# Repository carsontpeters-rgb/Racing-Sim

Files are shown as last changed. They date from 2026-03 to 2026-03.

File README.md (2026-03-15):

What is it?
Its a sim rig that I built from scratch. It has a steering wheel, gas, brake and clutch with a H pattern shifter. Its all built around a Teensy 4.1 that plugs straight into a PC via USB. The brake uses a load cell and a heavy spring to give it a realistic feel and the gas and clutch use position sensors with lighter springs. The steering wheel uses a magnetic encoder so it never wears out and its geared so you can get 720 degrees of rotation even though the sensor only measures 360. The shifter works with the same encoders, there is one for the X axis and one for the Y and they read the angles to see what gear its in.
How do you use it?
You use it by just plugging it in, the OLED screen will walk you through a calibration sequence so it knows where the gears are, where the steering wheel is and the pedal positions. It saves after so you dont need to do it again unless it starts acting up.
Why did I make it?
I made it because sim rigs are expensive and I figured I could make a nice one for cheaper, plus I learned a lot while working on the project and get a cool gaming controller out of it.
How do you build it?
Its a 3D printed rig with steel rods to support areas where just plastic would fail. The frame gets screw into my desk which is why there no way to mount it, it will be permant. Each pedal has a hall sensor and a magnet that measures how far the pedal is pressed and tells the microcontroller how much throttle to give, except the brake which uses a load cell run through a HX711 to amplify the signal. The steering column runs through 2 bearings with a gear in the middle so all the load goes through the frame and the gear turns the magnet to measure the angle. The H pattern shifter is similar to the wheel, it just has 2 encoders one for X and one for Y and based off those angles it tells the PC what gear its in. Its all run off 3.3V and a Teensy 4.1 with the code uploaded through Arduino IDE, you just have to change the USB type to keyboard mouse and joystick and hit upload.
Here is the onshape link for the cad
(https://cad.onshape.com/documents/68b4fea7a6f0c741230f520d/w/fb4024dbed9d682b8b255ca7/e/c212651a466c837dd5f70d13)
Note this desing wont work with Ps5 or Xbox unless you use a brooks wingman addappter

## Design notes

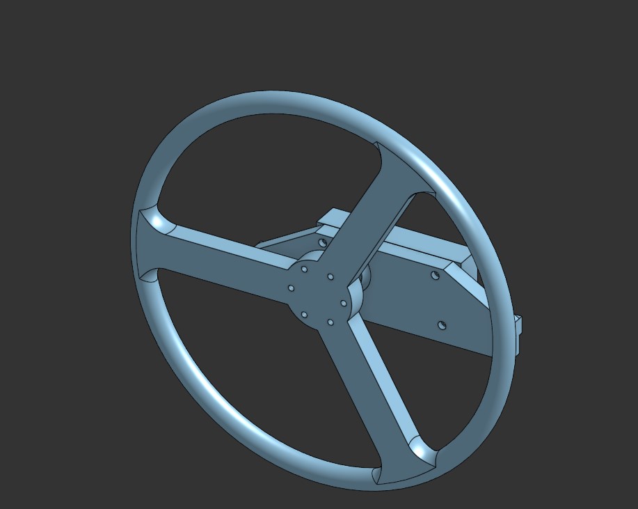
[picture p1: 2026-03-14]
Pictures/Steering.jpg

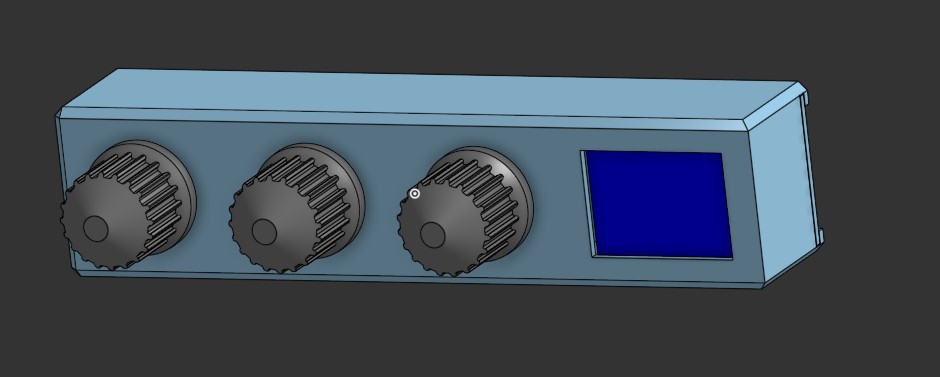
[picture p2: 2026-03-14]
Pictures/Display pannel.jpg

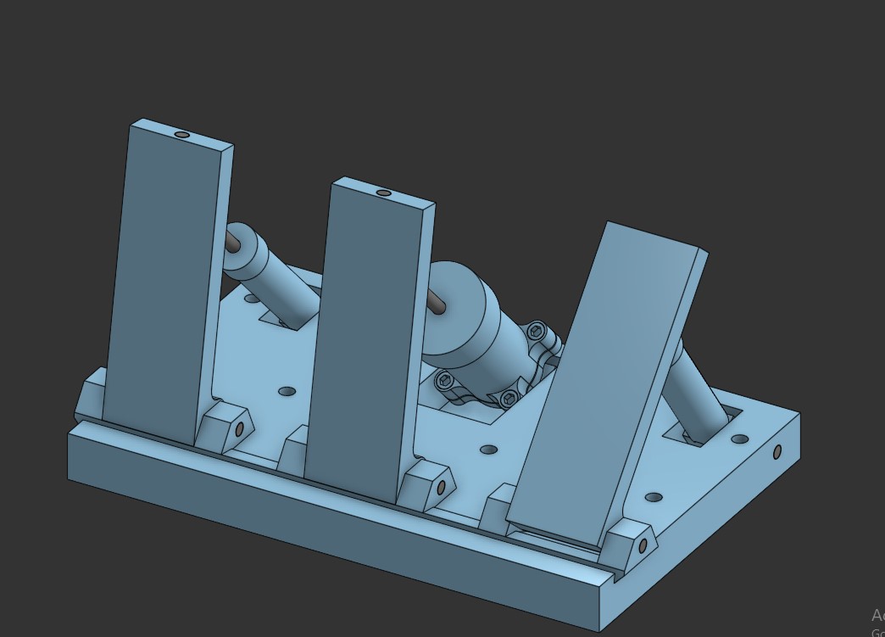
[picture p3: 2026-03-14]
Pictures/Pedals 2.jpg

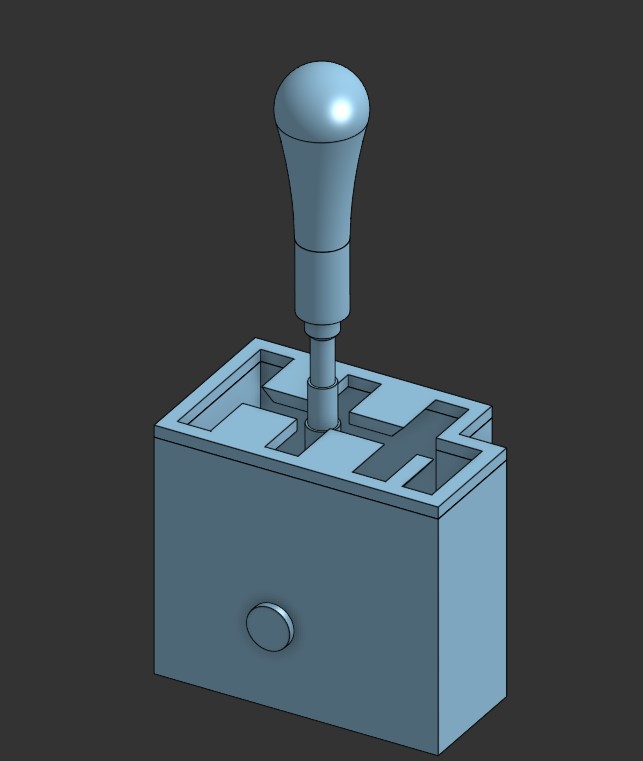
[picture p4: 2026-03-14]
Pictures/Stick.jpg

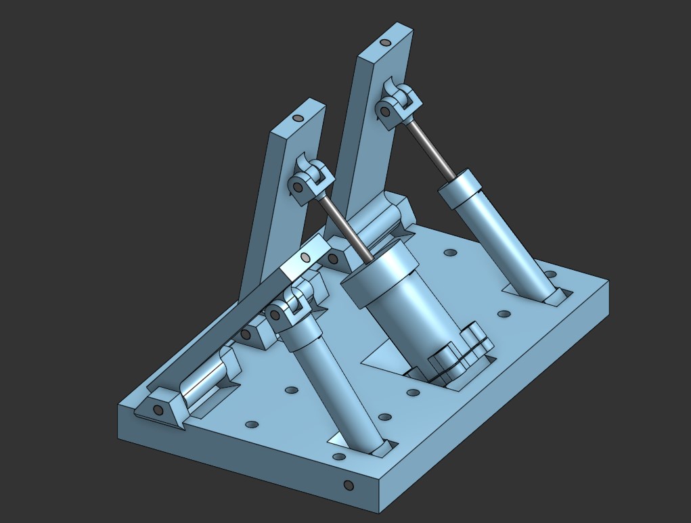
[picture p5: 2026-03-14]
Pictures/Pedals 1.jpg

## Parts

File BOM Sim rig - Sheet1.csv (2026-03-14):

Item Name | Discription | Quantity | Total Price | URL
Tension Springs | centering stick shift | 1 | $5.51 | https://www.aliexpress.com/item/1005009488489265.html?spm=a2g0o.cart.0.0.748638daWiuupG&mp=1
Rotery incoder Knob | setting ajutment knobs | 3 | $4.32 | https://www.aliexpress.com/item/1005008716778661.html?spm=a2g0o.cart.0.0.748638daWiuupG&mp=1
Oled Display | Display screen | 1 | $4.62 | https://www.aliexpress.com/item/1005006514489341.html?spm=a2g0o.cart.0.0.748638daWiuupG&mp=1
Steering wheel | Steering wheel | 1 | $42.57 | https://www.aliexpress.com/item/1005006066966347.html?spm=a2g0o.cart.0.0.748638daWiuupG&mp=1
HX711 | Load cell amplifier | 1 | $1.88 | https://www.aliexpress.com/item/1005006851380544.html?spm=a2g0o.cart.0.0.555038dasAW0UJ&mp=1
10Uf Capacitor | Capacitor | 1 | $4.46 | https://www.aliexpress.com/item/1005010409167964.html?spm=a2g0o.cart.0.0.555038dasAW0UJ&mp=1
Magnets | Magnets | 2 | $12.48 | https://www.aliexpress.com/item/1005010025118637.html?spm=a2g0o.cart.0.0.555038dasAW0UJ&mp=1
Ball Bearings | Bearings | 6 | $7.03 | https://www.aliexpress.com/item/10000314626783.html?spm=a2g0o.cart.0.0.555038dasAW0UJ&mp=1
49e Hall effect sensor | measures linear movement of magnets | 2 | $2.15 | https://www.aliexpress.com/item/32852539663.html?spm=a2g0o.cart.0.0.555038da9htNFP&mp=1
Load Cell | measures weight on break pedal | 1 | $9.18 | https://www.aliexpress.com/item/1005006039178981.html?spm=a2g0o.cart.0.0.555038da9htNFP&mp=1
100Nf Capacitors | Capacitors | 2 | $0.36 | https://www.aliexpress.com/item/1005006579533330.html?spm=a2g0o.cart.0.0.555038da9htNFP&mp=1
Teensy 4.1 | Micro Controller | 1 | $68.68 | https://www.aliexpress.com/item/1005004478114607.html?spm=a2g0o.cart.0.0.555038da9htNFP&mp=1
Magnetic Encoder | Measures Steering wheel rotation | 3 | $4.14 | https://www.aliexpress.com/item/1005008401280982.html?mp=1
TCA9548A | Ic2 Multiplexer | 1 | $0.57 | https://www.aliexpress.com/item/32904755017.html?spm=a2g0o.cart.0.0.555038da9htNFP&mp=1
Spring | Break reaturn Spring | 1 | $11.39 | https://www.aliexpress.com/item/1005007247817768.html?spm=a2g0o.cart.0.0.555038da9htNFP&mp=1
Spring | Gas+Clutch return spring | 2 | $8.49 | https://www.aliexpress.com/item/1005009816348235.html?spm=a2g0o.cart.0.0.555038da9htNFP&mp=1
Total Parts cost |  |  | $187.83
Total Parts cost after shipping+Tax |  |  | $236.00
Note all prices are in Cad

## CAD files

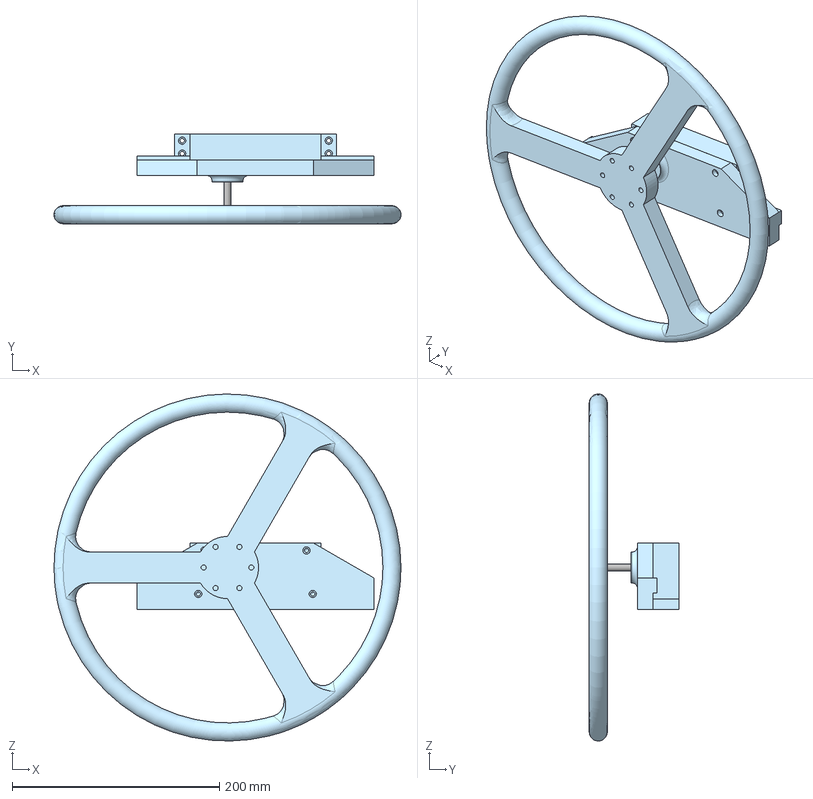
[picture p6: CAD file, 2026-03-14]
Cad Files/Assemblys/Steering wheel.step
335.0 x 86.5 x 335.0 mm
Spur gear (20 teeth)
Spur gear (10 teeth)

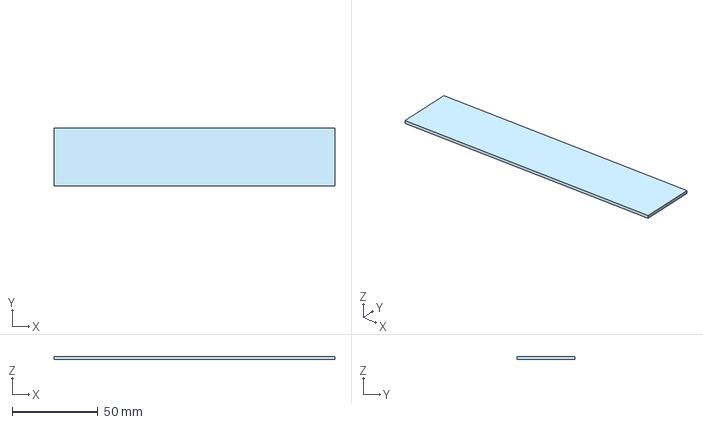
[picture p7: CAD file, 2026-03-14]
Cad Files/Control panel/Back pannel.step
163.5 x 33.5 x 1.75 mm

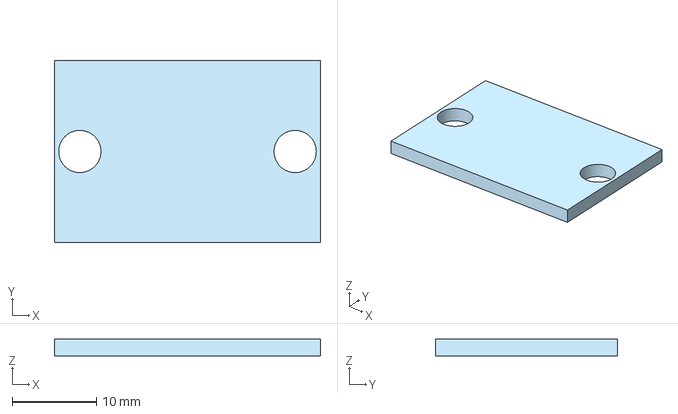
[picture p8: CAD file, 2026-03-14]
Cad Files/Electronics/IC2 Multiplexer.step
31.5 x 21.6 x 2.00 mm

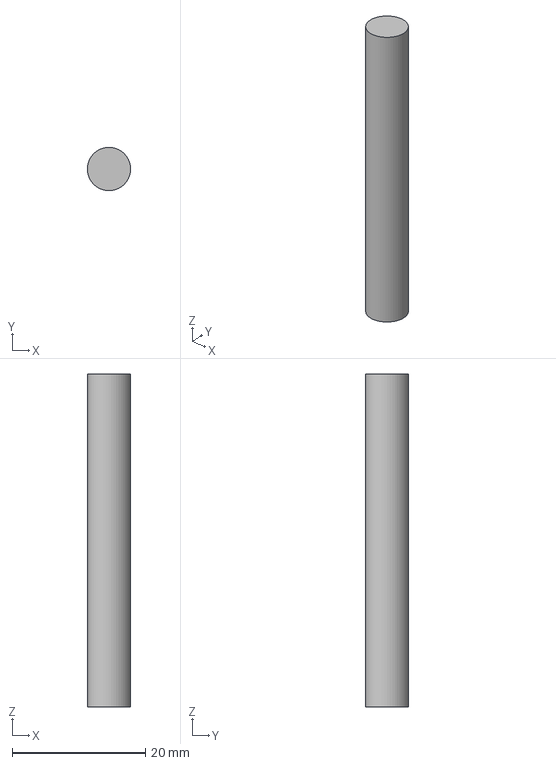
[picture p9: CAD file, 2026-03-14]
Cad Files/None Printed Parts/Steering Shaft.step
6.49 x 6.50 x 50.0 mm

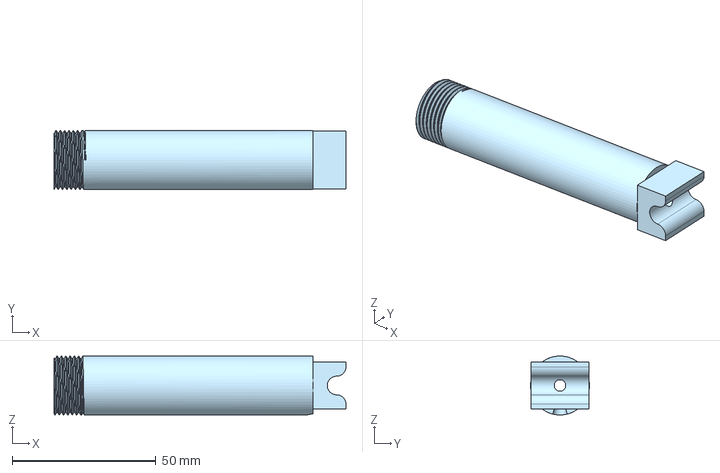
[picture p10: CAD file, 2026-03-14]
Cad Files/Pedals/Spring Cylinder.step
101.5 x 20.5 x 20.5 mm

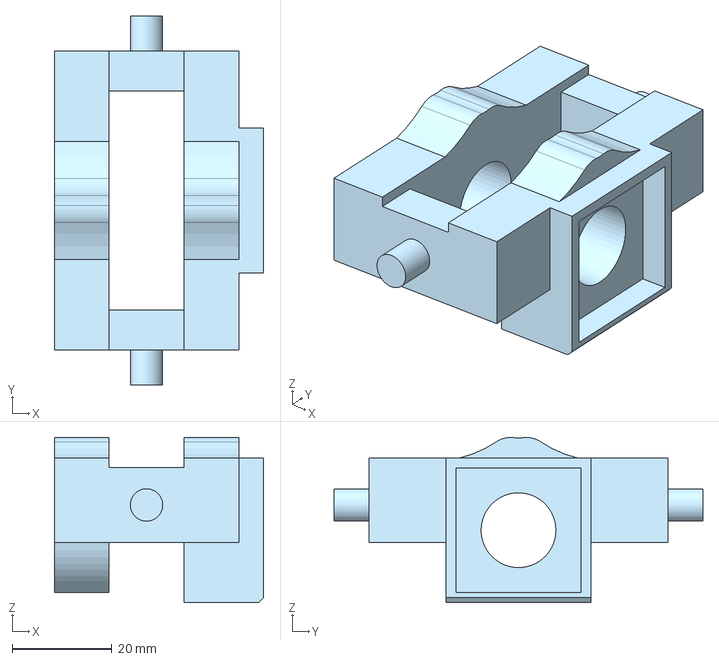
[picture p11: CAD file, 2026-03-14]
Cad Files/Shifter/Y-AXIS.step
42.0 x 74.0 x 33.1 mm

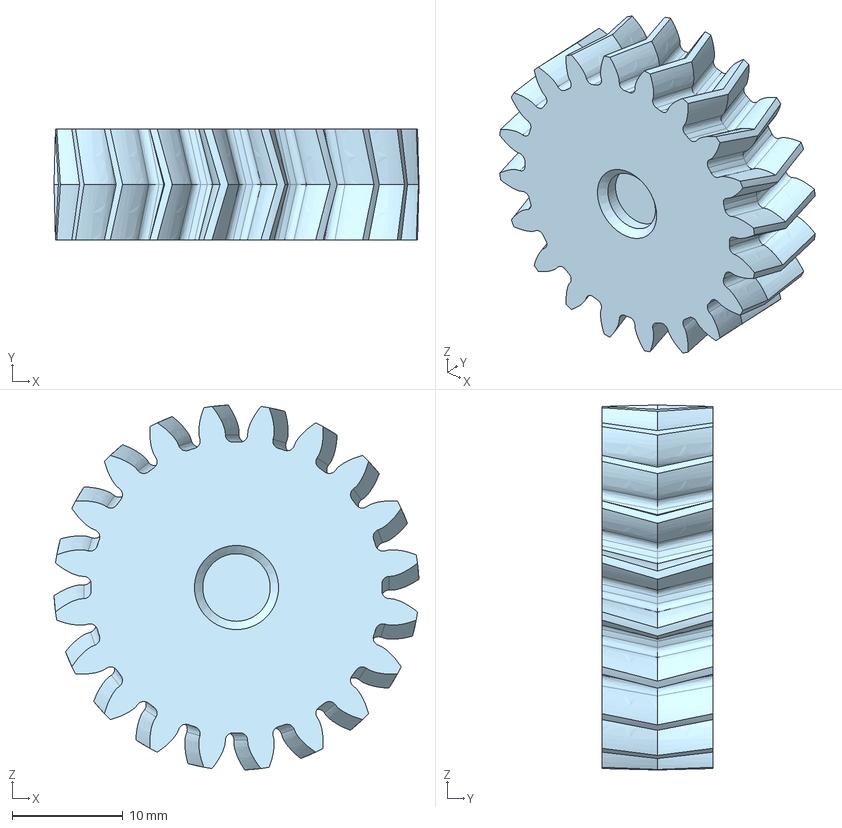
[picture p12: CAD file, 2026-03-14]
Cad Files/Steering Wheel/MAG GEAR.step
33.0 x 10.0 x 33.0 mm

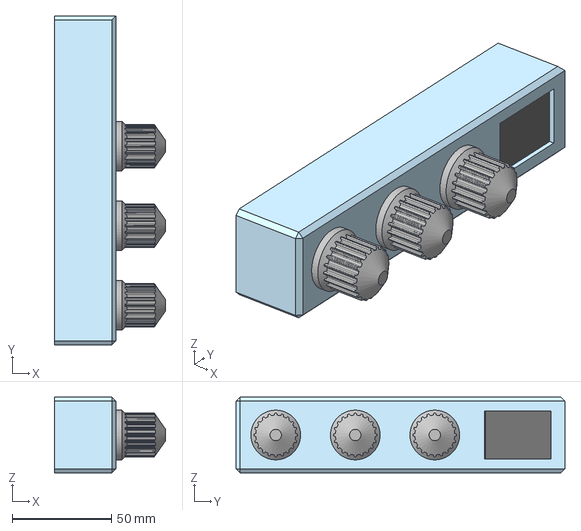
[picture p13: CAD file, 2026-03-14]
Cad Files/Assemblys/Display pannel.step
56.0 x 165.5 x 38.0 mm

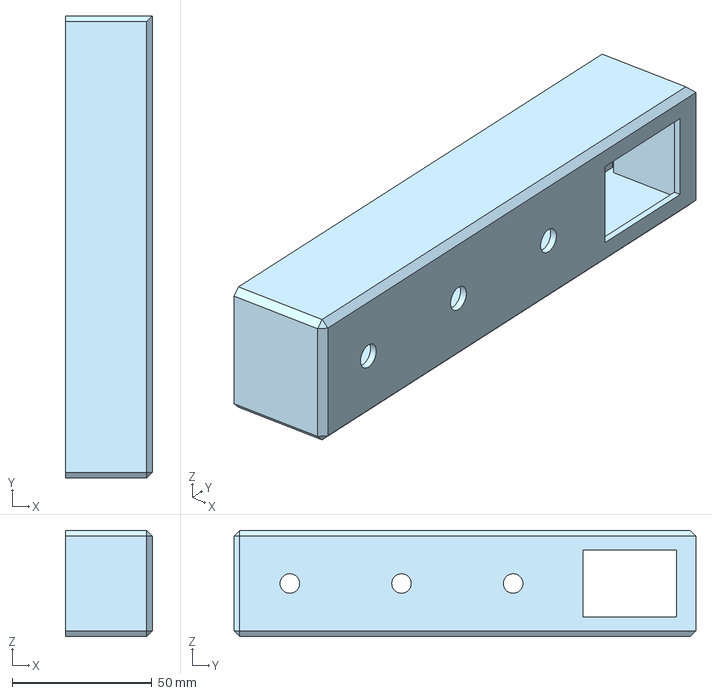
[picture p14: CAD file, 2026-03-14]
Cad Files/Control panel/Display Pannel.step
31.0 x 165.5 x 38.0 mm

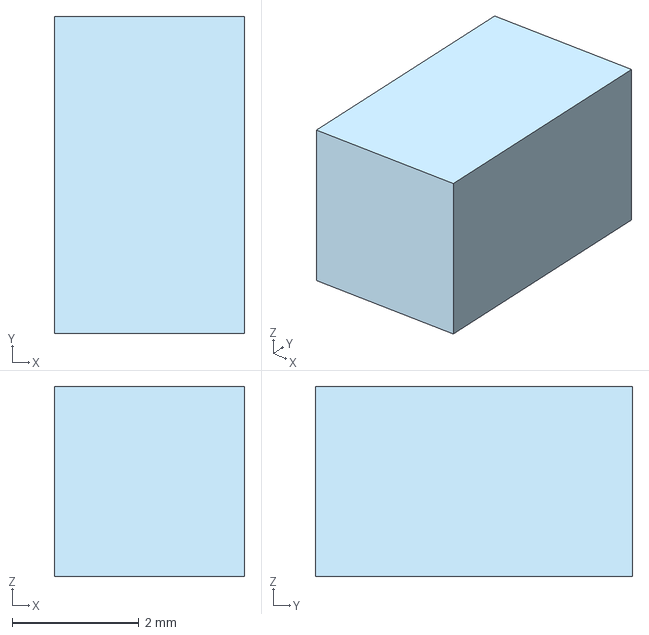
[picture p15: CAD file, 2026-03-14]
Cad Files/Electronics/Hall effect sensors.step
3.00 x 5.00 x 3.00 mm

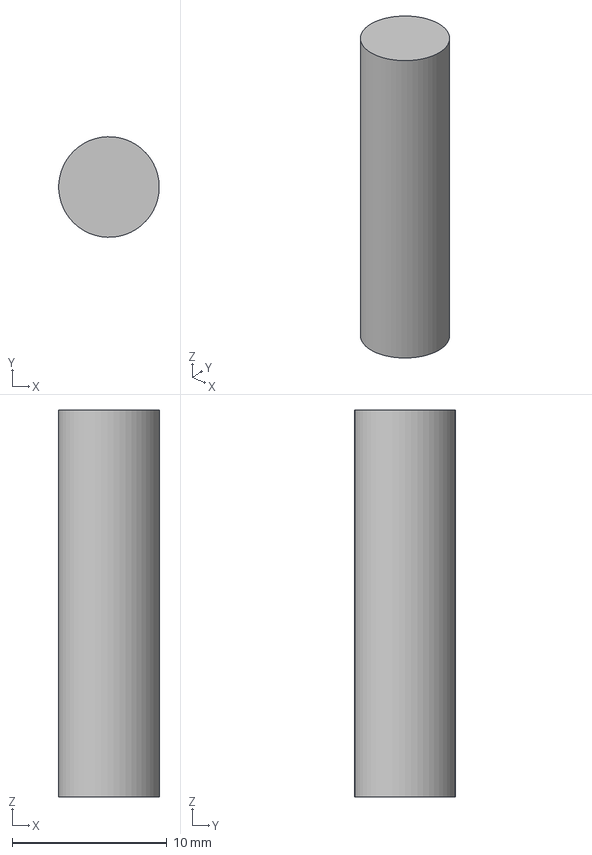
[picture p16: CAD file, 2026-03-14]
Cad Files/None Printed Parts/spring Pedal Mount rod Copy 1.step
6.49 x 6.50 x 25.0 mm

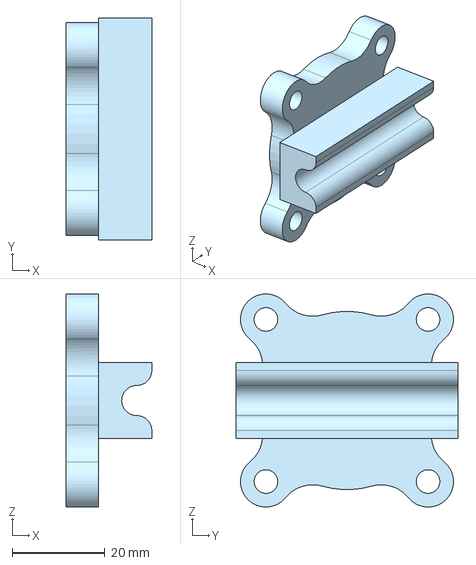
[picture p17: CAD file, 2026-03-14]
Cad Files/Pedals/Spring Cylinder brake mount.step
18.5 x 48.0 x 46.0 mm

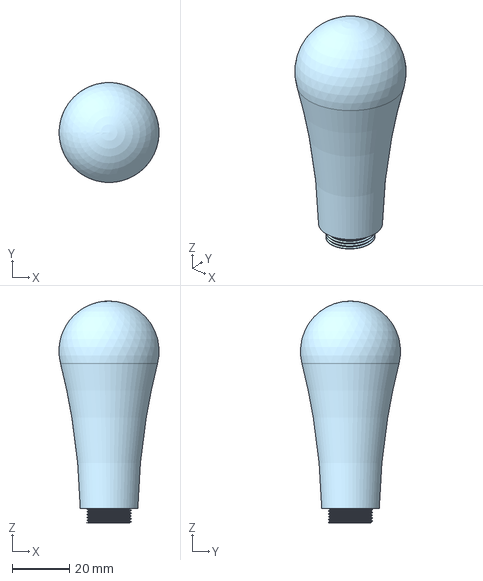
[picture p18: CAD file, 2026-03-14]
Cad Files/Shifter/Shifter Head.step
34.9 x 34.9 x 77.5 mm

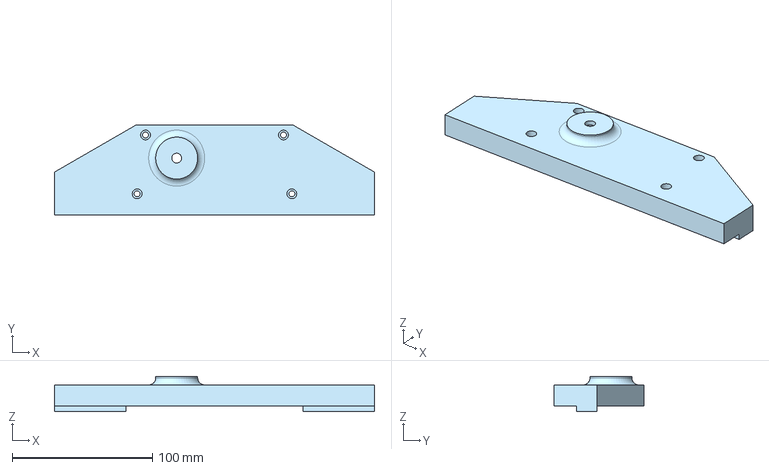
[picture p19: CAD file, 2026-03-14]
Cad Files/Steering Wheel/Steering cover.step
228.5 x 64.0 x 25.0 mm

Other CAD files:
Cad Files/Assemblys/Stick (1).step
Cad Files/Control panel/Knobs.step
Cad Files/Electronics/Rotery encoders.step
Cad Files/None Printed Parts/spring base Mount rod.step
Cad Files/Assemblys/Pedals.step
Cad Files/Electronics/AS5600.step
Cad Files/Electronics/HX711.step
Cad Files/Electronics/Load Cell.step
Cad Files/Electronics/Oled.step
Cad Files/Electronics/teensy 4.1.step
Cad Files/None Printed Parts/Bearing.step
Cad Files/None Printed Parts/Pedal Rod.step
Cad Files/None Printed Parts/Pedal core rod.step
Cad Files/None Printed Parts/Wheel.step
Cad Files/Pedals/Bolt.step
Cad Files/Pedals/Brake cover.step
Cad Files/Pedals/Cover.step
Cad Files/Pedals/Gas, Clutch and Break Pedal.step
Cad Files/Pedals/Pedal Mounts.step
Cad Files/Pedals/Spring Cylinder brake.step
Cad Files/Pedals/Spring Rod Brake.step
Cad Files/Pedals/Spring Rod.step
Cad Files/Shifter/H Plate.step
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

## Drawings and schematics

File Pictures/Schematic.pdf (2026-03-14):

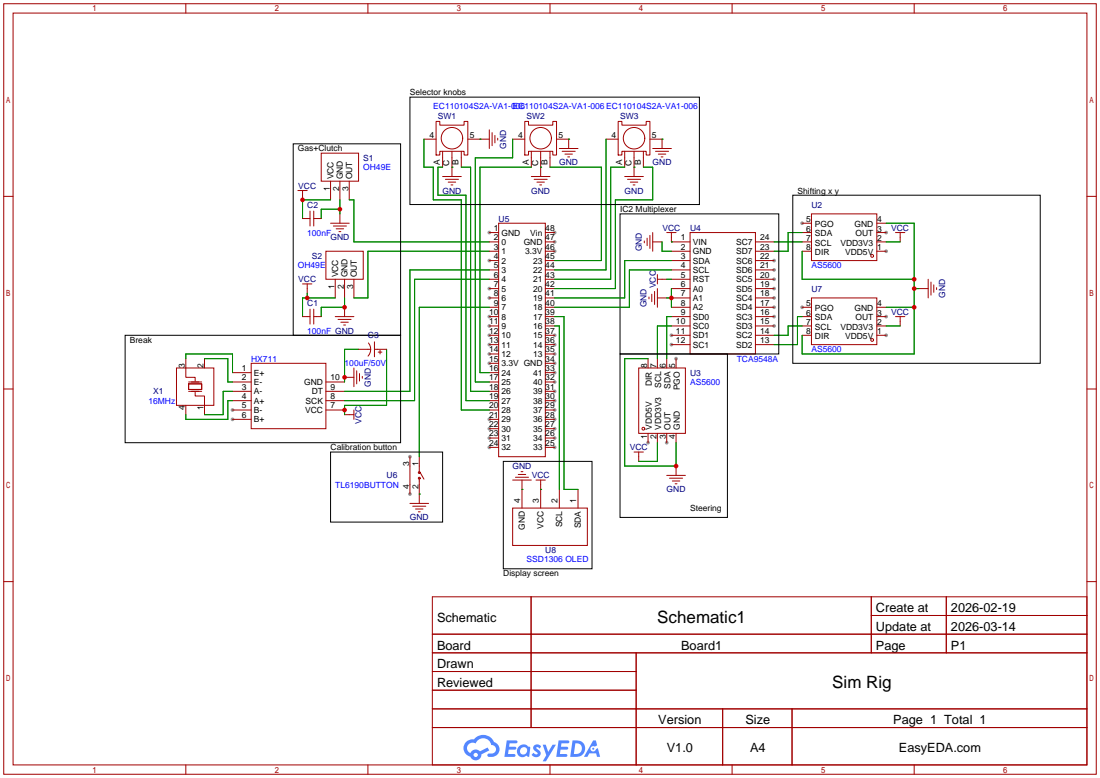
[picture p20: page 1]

Schematic | Schematic1 | Create at | 2026-02-19

Update at | 2026-03-14

Board | Board1 | Page | P1
Drawn | | Sim Rig
Reviewed

Version | Size | Page 1 Total 1
V1.0 | A4 | EasyEDA.com

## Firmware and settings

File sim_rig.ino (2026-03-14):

#include <Wire.h>
#include <HX711.h>
#include <EEPROM.h>
#include <Adafruit_GFX.h>
#include <Adafruit_SSD1306.h>

#define OLED_WIDTH    128
#define OLED_HEIGHT   64
#define OLED_ADDR     0x3C
#define OLED_RESET    -1

Adafruit_SSD1306 oled(OLED_WIDTH, OLED_HEIGHT, &Wire1, OLED_RESET);

#define PIN_GAS         A0
#define PIN_CLUTCH      A1
#define PIN_HX_DT       3
#define PIN_HX_SCK      4
#define PIN_CAL_BUTTON  7

struct PedalCal  { int minVal, maxVal; };
struct SteerCal  { uint16_t minVal, maxVal; };
struct BrakeCal  { long maxForce; };

struct ShifterCal {
  uint16_t xMin, xMax;
  uint16_t yMin, yMax;
  uint16_t gearX[6];
  uint16_t gearY[6];
};

PedalCal   gasCal, clutchCal;
SteerCal   steerCal;
BrakeCal   brakeCal;
ShifterCal shiftCal;

#if !defined(USB_KEYBOARDJOYSTICK) && !defined(USB_HID) && !defined(USB_JOYSTICK)
  #error "Set Tools > USB Type > Keyboard + Mouse + Joystick before compiling!"
#endif

HX711 brake;

#define TCA_ADDR       0x70
#define AS5600_ADDR    0x36
#define TCA_CH_STEER   0
#define TCA_CH_SHIFT_X 1
#define TCA_CH_SHIFT_Y 2

void tcaSelect(uint8_t ch) {
  Wire.beginTransmission(TCA_ADDR);
  Wire.write(1 << ch);
  Wire.endTransmission();
}

void tcaNone() {
  Wire.beginTransmission(TCA_ADDR);
  Wire.write(0);
  Wire.endTransmission();
}

uint16_t readAS5600() {
  Wire.beginTransmission(AS5600_ADDR);
  Wire.write(0x0C);
  Wire.endTransmission(false);
  Wire.requestFrom(AS5600_ADDR, 2);
  if (Wire.available() >= 2) {
    uint16_t h = Wire.read();
    uint16_t l = Wire.read();
    return ((h << 8) | l) & 0x0FFF;
  }
  return 2048;
}

uint16_t readSteering() { tcaSelect(TCA_CH_STEER);   return readAS5600(); }
uint16_t readShiftX()   { tcaSelect(TCA_CH_SHIFT_X); return readAS5600(); }
uint16_t readShiftY()   { tcaSelect(TCA_CH_SHIFT_Y); return readAS5600(); }

#define EEPROM_MAGIC       0
#define EEPROM_GAS_MIN     2
#define EEPROM_GAS_MAX     6
#define EEPROM_CLUTCH_MIN  10
#define EEPROM_CLUTCH_MAX  14
#define EEPROM_BRAKE_MAX   26
#define EEPROM_STEER_MIN   30
#define EEPROM_STEER_MAX   34
#define EEPROM_SHIFTX_MIN  38
#define EEPROM_SHIFTX_MAX  42
#define EEPROM_SHIFTY_MIN  46
#define EEPROM_SHIFTY_MAX  50
#define EEPROM_GEAR_BASE   54
#define EEPROM_MAGIC_VAL   0xA55A

template<typename T> void eepromWrite(int addr, T val) { EEPROM.put(addr, val); }
template<typename T> T   eepromRead(int addr)          { T v; EEPROM.get(addr, v); return v; }

bool eepromValid() { return eepromRead<uint16_t>(EEPROM_MAGIC) == EEPROM_MAGIC_VAL; }

void loadCalibration() {
  gasCal.minVal     = eepromRead<int>(EEPROM_GAS_MIN);
  gasCal.maxVal     = eepromRead<int>(EEPROM_GAS_MAX);
  clutchCal.minVal  = eepromRead<int>(EEPROM_CLUTCH_MIN);
  clutchCal.maxVal  = eepromRead<int>(EEPROM_CLUTCH_MAX);
  brakeCal.maxForce = eepromRead<long>(EEPROM_BRAKE_MAX);
  steerCal.minVal   = eepromRead<uint16_t>(EEPROM_STEER_MIN);
  steerCal.maxVal   = eepromRead<uint16_t>(EEPROM_STEER_MAX);
  shiftCal.xMin     = eepromRead<uint16_t>(EEPROM_SHIFTX_MIN);
  shiftCal.xMax     = eepromRead<uint16_t>(EEPROM_SHIFTX_MAX);
  shiftCal.yMin     = eepromRead<uint16_t>(EEPROM_SHIFTY_MIN);
  shiftCal.yMax     = eepromRead<uint16_t>(EEPROM_SHIFTY_MAX);
  for (int i = 0; i < 6; i++) {
    shiftCal.gearX[i] = eepromRead<uint16_t>(EEPROM_GEAR_BASE + i * 4);
    shiftCal.gearY[i] = eepromRead<uint16_t>(EEPROM_GEAR_BASE + i * 4 + 2);
  }
}

void saveCalibration() {
  eepromWrite(EEPROM_MAGIC,      (uint16_t)EEPROM_MAGIC_VAL);
  eepromWrite(EEPROM_GAS_MIN,    gasCal.minVal);
  eepromWrite(EEPROM_GAS_MAX,    gasCal.maxVal);
  eepromWrite(EEPROM_CLUTCH_MIN, clutchCal.minVal);
  eepromWrite(EEPROM_CLUTCH_MAX, clutchCal.maxVal);
  eepromWrite(EEPROM_BRAKE_MAX,  brakeCal.maxForce);
  eepromWrite(EEPROM_STEER_MIN,  steerCal.minVal);
  eepromWrite(EEPROM_STEER_MAX,  steerCal.maxVal);
  eepromWrite(EEPROM_SHIFTX_MIN, shiftCal.xMin);
  eepromWrite(EEPROM_SHIFTX_MAX, shiftCal.xMax);
  eepromWrite(EEPROM_SHIFTY_MIN, shiftCal.yMin);
  eepromWrite(EEPROM_SHIFTY_MAX, shiftCal.yMax);
  for (int i = 0; i < 6; i++) {
    eepromWrite(EEPROM_GEAR_BASE + i * 4,     shiftCal.gearX[i]);
    eepromWrite(EEPROM_GEAR_BASE + i * 4 + 2, shiftCal.gearY[i]);
  }
}

void applyDefaults() {
  gasCal    = {50, 970};
  clutchCal = {50, 970};
  brakeCal.maxForce = 50000L;
  steerCal  = {200, 3895};
  shiftCal.xMin = 100; shiftCal.xMax = 3995;
  shiftCal.yMin = 100; shiftCal.yMax = 3995;
  shiftCal.gearX[0] = 800;  shiftCal.gearY[0] = 3000;
  shiftCal.gearX[1] = 800;  shiftCal.gearY[1] = 1000;
  shiftCal.gearX[2] = 2048; shiftCal.gearY[2] = 3000;
  shiftCal.gearX[3] = 2048; shiftCal.gearY[3] = 1000;
  shiftCal.gearX[4] = 3200; shiftCal.gearY[4] = 3000;
  shiftCal.gearX[5] = 3200; shiftCal.gearY[5] = 1000;
}

#define FILTER_SIZE 8

class RollingAvg {
  int buf[FILTER_SIZE] = {};
  int idx = 0;
  long sum = 0;
  int count = 0;
public:
  int update(int val) {
    sum -= buf[idx];
    buf[idx] = val;
    sum += val;
    idx = (idx + 1) % FILTER_SIZE;
    if (count < FILTER_SIZE) count++;
    return sum / count;
  }
};

RollingAvg gasFilter, clutchFilter;

#define BRAKE_EXPONENT 2.0f

int scaleBrake(long raw) {
  float n = constrain((float)raw / brakeCal.maxForce, 0.0f, 1.0f);
  return (int)(pow(n, BRAKE_EXPONENT) * 1023.0f);
}

void oledClear() {
  oled.clearDisplay();
  oled.setTextColor(SSD1306_WHITE);
  oled.cp437(true);
}

void oledPrompt(const char* action, const char* instruction) {
  oledClear();
  oled.fillRect(0, 0, 128, 12, SSD1306_WHITE);
  oled.setTextColor(SSD1306_BLACK);
  oled.setTextSize(1);
  oled.setCursor(2, 2);
  oled.print("SIM RIG  CALIBRATION");
  oled.setTextColor(SSD1306_WHITE);
  oled.setTextSize(2);
  int16_t x1, y1; uint16_t w, h;
  oled.getTextBounds(action, 0, 0, &x1, &y1, &w, &h);
  oled.setCursor((128 - w) / 2, 18);
  oled.print(action);
  oled.setTextSize(1);
  oled.setCursor(0, 50);
  oled.print(instruction);
  oled.display();
}

void oledBig(const char* top, const char* symbol, const char* bottom) {
  oledClear();
  oled.setTextSize(1);
  oled.setCursor(0, 0);
  oled.print(top);
  oled.setTextSize(3);
  int16_t x1, y1; uint16_t w, h;
  oled.getTextBounds(symbol, 0, 0, &x1, &y1, &w, &h);
  oled.setCursor((128 - w) / 2, 20);
  oled.print(symbol);
  oled.setTextSize(1);
  oled.setCursor(0, 56);
  oled.print(bottom);
  oled.display();
}

void oledCountdown(const char* label, int durationMs) {
  int steps = 20;
  int stepMs = durationMs / steps;
  for (int i = 0; i <= steps; i++) {
    oledClear();
    oled.setTextSize(1);
    oled.setCursor(0, 0);
    oled.print(label);
    oled.setCursor(0, 14);
    oled.print("Hold still...");
    oled.drawRect(0, 48, 128, 12, SSD1306_WHITE);
    oled.fillRect(2, 50, (int)(124.0f * i / steps), 8, SSD1306_WHITE);
    oled.display();
    delay(stepMs);
  }
}

void oledSaved(const char* what) {
  oledClear();
  oled.setTextSize(1);
  oled.setCursor(20, 10);
  oled.print("SAVED");
  oled.setTextSize(2);
  oled.setCursor(0, 28);
  oled.print(what);
  oled.display();
  delay(600);
}

void waitButton(const char* action, const char* instruction) {
  oledPrompt(action, instruction);
  while (digitalRead(PIN_CAL_BUTTON) == LOW) delay(10);
  while (digitalRead(PIN_CAL_BUTTON) == HIGH) delay(10);
  delay(50);
  while (digitalRead(PIN_CAL_BUTTON) == LOW) delay(10);
}

void calPedal(const char* name, const char* symbol, int pin, PedalCal &cal) {
  oledBig(name, symbol, "RELEASE fully, press BTN");
  while (digitalRead(PIN_CAL_BUTTON) == HIGH) delay(10);
  delay(50);
  while (digitalRead(PIN_CAL_BUTTON) == LOW) delay(10);
  oledCountdown(name, 800);
  cal.minVal = analogRead(pin);
  oledSaved("MIN OK");

  oledBig(name, symbol, "PRESS FULL, press BTN");
  while (digitalRead(PIN_CAL_BUTTON) == HIGH) delay(10);
  delay(50);
  while (digitalRead(PIN_CAL_BUTTON) == LOW) delay(10);
  oledCountdown(name, 800);
  cal.maxVal = analogRead(pin);
  oledSaved("MAX OK");
}

void calBrake() {
  oledBig("BRAKE", "---", "Do NOT touch. Taring...");
  delay(1000);
  brake.tare();
  oledSaved("TARE OK");

  oledBig("BRAKE", "|||", "STOMP IT, press BTN");
  while (digitalRead(PIN_CAL_BUTTON) == HIGH) delay(10);
  delay(50);
  while (digitalRead(PIN_CAL_BUTTON) == LOW) delay(10);
  oledCountdown("BRAKE MAX FORCE", 800);
  brakeCal.maxForce = abs(brake.read());
  oledSaved("FORCE OK");
}

void calSteering() {
  oledBig("STEER", "<<<", "FULL LEFT, press BTN");
  while (digitalRead(PIN_CAL_BUTTON) == HIGH) delay(10);
  delay(50);
  while (digitalRead(PIN_CAL_BUTTON) == LOW) delay(10);
  oledCountdown("LEFT LOCK", 800);
  steerCal.minVal = readSteering();
  oledSaved("LEFT OK");

  oledBig("STEER", ">>>", "FULL RIGHT, press BTN");
  while (digitalRead(PIN_CAL_BUTTON) == HIGH) delay(10);
  delay(50);
  while (digitalRead(PIN_CAL_BUTTON) == LOW) delay(10);
  oledCountdown("RIGHT LOCK", 800);
  steerCal.maxVal = readSteering();
  oledSaved("RIGHT OK");
}

void calShifter() {
  shiftCal.xMin = 4095; shiftCal.xMax = 0;
  shiftCal.yMin = 4095; shiftCal.yMax = 0;

  const char* gearSymbols[] = {"1", "2", "3", "4", "5", "6"};
  const char* gearLabels[]  = {
    "Engage 1st, press BTN",
    "Engage 2nd, press BTN",
    "Engage 3rd, press BTN",
    "Engage 4th, press BTN",
    "Engage 5th, press BTN",
    "Engage 6th, press BTN"
  };

  for (int g = 0; g < 6; g++) {
    oledBig("SHIFTER", gearSymbols[g], gearLabels[g]);
    while (digitalRead(PIN_CAL_BUTTON) == HIGH) delay(10);
    delay(50);
    while (digitalRead(PIN_CAL_BUTTON) == LOW) delay(10);
    oledCountdown("HOLD GEAR", 600);

    uint16_t x = readShiftX();
    uint16_t y = readShiftY();
    shiftCal.gearX[g] = x;
    shiftCal.gearY[g] = y;
    if (x < shiftCal.xMin) shiftCal.xMin = x;
    if (x > shiftCal.xMax) shiftCal.xMax = x;
    if (y < shiftCal.yMin) shiftCal.yMin = y;
    if (y > shiftCal.yMax) shiftCal.yMax = y;

    char buf[12];
    snprintf(buf, sizeof(buf), "GEAR %d OK", g + 1);
    oledSaved(buf);
  }

  tcaNone();
}

void runCalibration() {
  oledClear();
  oled.setTextSize(1);
  oled.setCursor(10, 5);
  oled.print("SIM RIG v4.0");
  oled.setCursor(5, 20);
  oled.print("CALIBRATION MODE");
  oled.setCursor(0, 38);
  oled.print("Press BTN to start");
  oled.setCursor(0, 50);
  oled.print("each step when ready");
  oled.display();
  delay(2000);

  calPedal("GAS",    "G", PIN_GAS,    gasCal);
  calPedal("CLUTCH", "C", PIN_CLUTCH, clutchCal);
  calBrake();
  calSteering();
  calShifter();

  saveCalibration();

  oledClear();
  oled.setTextSize(2);
  oled.setCursor(10, 10);
  oled.print("ALL DONE");
  oled.setTextSize(1);
  oled.setCursor(5, 40);
  oled.print("Saved. Restarting...");
  oled.display();
  delay(2000);

  SCB_AIRCR = 0x05FA0004;
}

int detectGear(uint16_t x, uint16_t y) {
  uint16_t xMid      = (shiftCal.xMin + shiftCal.xMax) / 2;
  uint16_t yMid      = (shiftCal.yMin + shiftCal.yMax) / 2;
  uint16_t xDeadzone = (shiftCal.xMax - shiftCal.xMin) / 8;
  uint16_t yDeadzone = (shiftCal.yMax - shiftCal.yMin) / 6;

  if (abs((int)x - (int)xMid) < xDeadzone &&
      abs((int)y - (int)yMid) < yDeadzone)
    return 0;

  int      bestGear = 0;
  uint32_t bestDist = UINT32_MAX;

  for (int g = 0; g < 6; g++) {
    int dx = (int)x - (int)shiftCal.gearX[g];
    int dy = (int)y - (int)shiftCal.gearY[g];
    uint32_t dist = (uint32_t)(dx*dx) + (uint32_t)(dy*dy);
    if (dist < bestDist) {
      bestDist = dist;
      bestGear = g + 1;
    }
  }

  uint32_t maxAllowed = (uint32_t)(shiftCal.xMax - shiftCal.xMin) * 300;
  return (bestDist < maxAllowed) ? bestGear : 0;
}

int lastDisplayGear = -1;

void updateDisplay(int gear, bool reverse) {
  int displayGear = reverse ? -1 : gear;
  if (displayGear == lastDisplayGear) return;
  lastDisplayGear = displayGear;

  oledClear();

  oled.fillRect(0, 0, 128, 11, SSD1306_WHITE);
  oled.setTextColor(SSD1306_BLACK);
  oled.setTextSize(1);
  oled.setCursor(35, 2);
  oled.print("SIM RIG");

  oled.setTextColor(SSD1306_WHITE);

  if (reverse) {
    oled.setTextSize(4);
    oled.setCursor(44, 16);
    oled.print("R");
  } else if (gear == 0) {
    oled.setTextSize(4);
    oled.setCursor(44, 16);
    oled.print("N");
  } else {
    oled.setTextSize(4);
    char buf[3];
    snprintf(buf, sizeof(buf), "%d", gear);
    int16_t x1, y1; uint16_t w, h;
    oled.getTextBounds(buf, 0, 0, &x1, &y1, &w, &h);
    oled.setCursor((128 - w) / 2, 16);
    oled.print(buf);
  }

  oled.drawLine(0, 55, 128, 55, SSD1306_WHITE);
  oled.setTextSize(1);
  oled.setCursor(0, 57);
  oled.print("GEAR");
  oled.setCursor(90, 57);
  oled.print("v4.0");

  oled.display();
}

void setup() {
  Serial.begin(115200);

  Wire.begin();
  Wire.setClock(400000);

  Wire1.begin();
  Wire1.setClock(400000);

  if (!oled.begin(SSD1306_SWITCHCAPVCC, OLED_ADDR)) {
    Serial.println("OLED not found");
  } else {
    oledClear();
    oled.setTextSize(2);
    oled.setCursor(10, 8);
    oled.print("SIM RIG");
    oled.setTextSize(1);
    oled.setCursor(35, 30);
    oled.print("v4.0");
    oled.setCursor(10, 48);
    oled.print("Teensy 4.1");
    oled.display();
    delay(1500);
  }

  pinMode(PIN_CAL_BUTTON, INPUT_PULLUP);

  brake.begin(PIN_HX_DT, PIN_HX_SCK);
  brake.set_gain(128);

  if (eepromValid()) {
    loadCalibration();
    oledClear();
    oled.setTextSize(1);
    oled.setCursor(10, 20);
    oled.print("Cal loaded OK");
    oled.setCursor(5, 36);
    oled.print("Hold BTN to recal");
    oled.display();
    delay(1200);
  } else {
    applyDefaults();
    oledClear();
    oled.setTextSize(1);
    oled.setCursor(0, 10);
    oled.print("No calibration found");
    oled.setCursor(0, 26);
    oled.print("Hold BTN at boot to");
    oled.setCursor(0, 38);
    oled.print("run calibration");
    oled.display();
    delay(2000);
  }

  delay(200);
  if (digitalRead(PIN_CAL_BUTTON) == LOW) {
    delay(500);
    if (digitalRead(PIN_CAL_BUTTON) == LOW) {
      runCalibration();
    }
  }

  brake.tare();
  tcaNone();

  Joystick.useManualSend(true);

  updateDisplay(0, false);
}

void loop() {

  int gas  = gasFilter.update(analogRead(PIN_GAS));
  int clut = clutchFilter.update(analogRead(PIN_CLUTCH));

  gas  = constrain(map(gas,  gasCal.minVal,    gasCal.maxVal,    0, 1023), 0, 1023);
  clut = constrain(map(clut, clutchCal.minVal, clutchCal.maxVal, 0, 1023), 0, 1023);

  int brakeOut = 0;
  if (brake.is_ready()) {
    brakeOut = scaleBrake(abs(brake.read()));
  }

  uint16_t steerRaw = readSteering();
  int steerOut = constrain(
    map(steerRaw, steerCal.minVal, steerCal.maxVal, -32767, 32767),
    -32767, 32767
  );

  uint16_t shiftX = readShiftX();
  uint16_t shiftY = readShiftY();
  tcaNone();

  int  gear    = detectGear(shiftX, shiftY);
  bool reverse = (shiftY > shiftCal.yMax - 100);

  updateDisplay(gear, reverse);

  int steerSend = map(steerOut, -32767, 32767, 0, 1023);
  Joystick.X(steerSend);
  Joystick.Y(gas);
  Joystick.Z(brakeOut);
  Joystick.Zrotate(clut);

  for (int i = 0; i < 6; i++)
    Joystick.button(i + 1, gear == (i + 1));

  Joystick.button(7, reverse);

  Joystick.send_now();

  delay(4);
}
